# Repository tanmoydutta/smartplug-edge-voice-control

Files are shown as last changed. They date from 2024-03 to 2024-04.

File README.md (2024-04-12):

# A Module to hack a smart plug with Voice control, using Voice Recognition with Edge Analytics
Orthosie is a NINA-B306 powered Smart Plug controller module. The module contains basic circuitry for interfacing and programming and a PDM microphone for Speech recognition. 



This is a replacement / hacking module for modern smart plugs using ESP02S or CB2S modules from Tuya.


The diagram below shows the pinout of the module including programming and debug contact interfaces (USB Serial and Software Debug)
<p align="center">
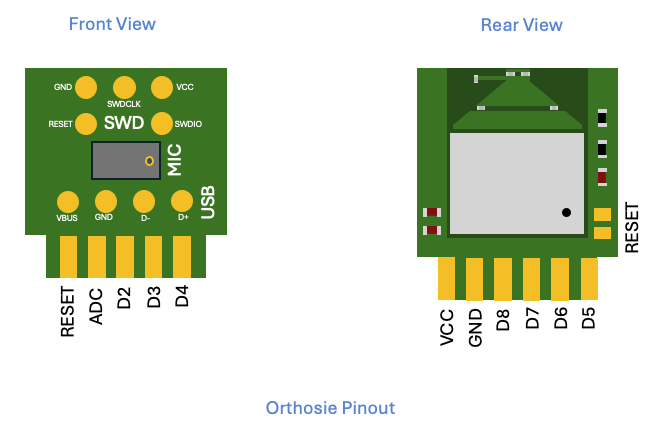
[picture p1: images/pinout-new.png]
Pinout Orthosie pinout
  
</p>

The contact interfaces (SWD and USB) can be connected to programming interface and devices using Pogo pin connectors with the help of suitable clips as shown below in the image.
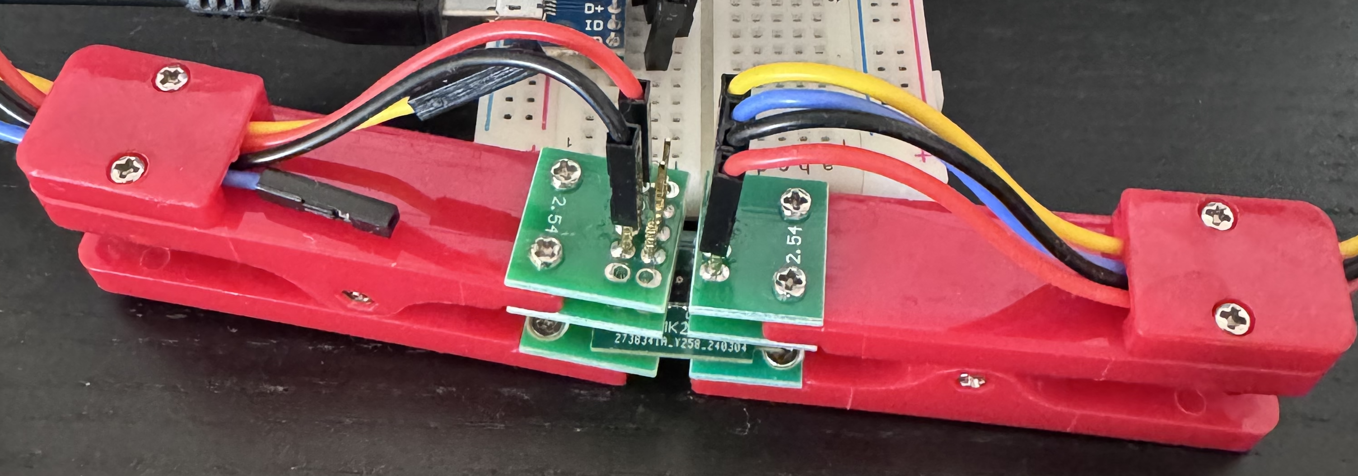
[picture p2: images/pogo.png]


The purpose of this module is to add a 'voice recognition on edge' capability to a Smart Plug. The NINA module also provides BLE capability and makes communication and control via BLE also possible.
<p align="center">
  Factory installed
  Hacked!
</p>

This is an Open Source Hardware certified by OSHWA - 

<p align="center">
  <a href="https://certification.oshwa.org/nl000019.html">
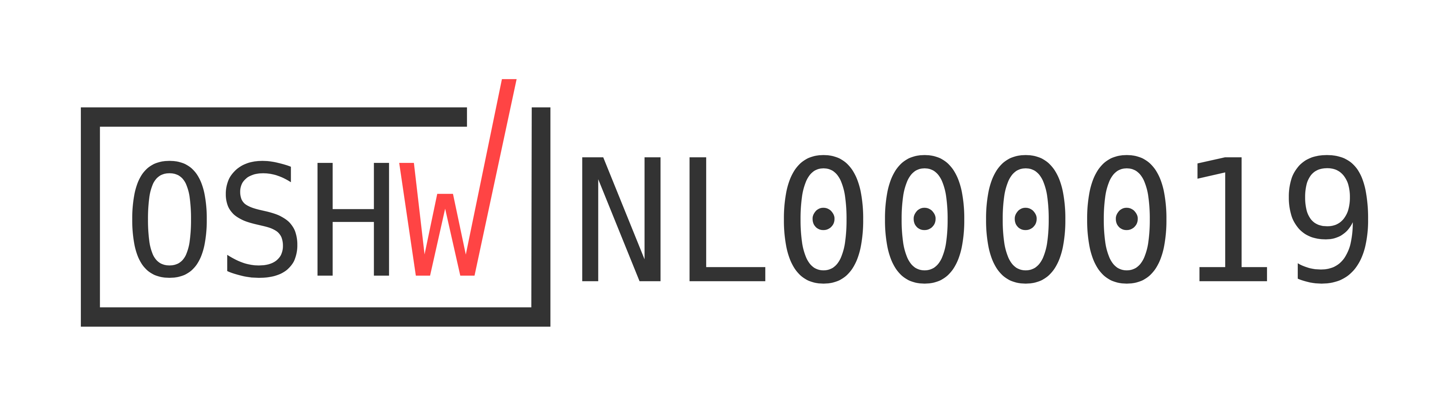
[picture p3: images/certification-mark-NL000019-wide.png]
OSHWA OSHWA Certification
    
  </a>
</p>



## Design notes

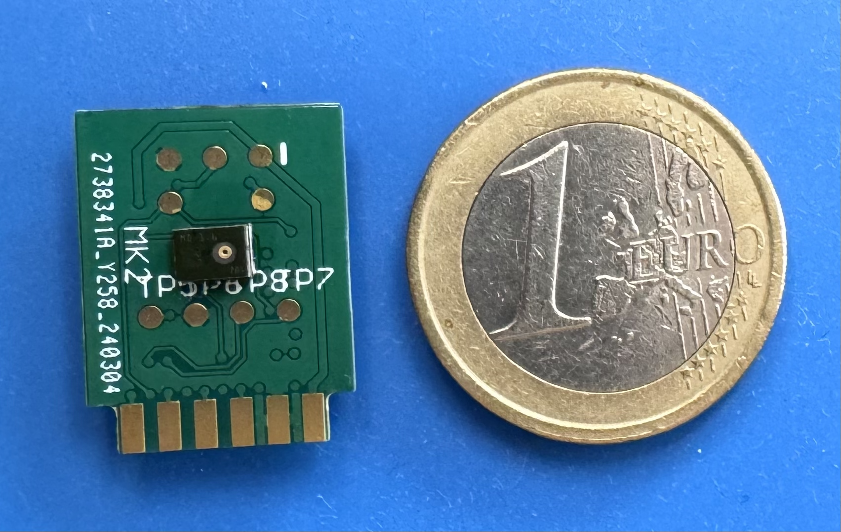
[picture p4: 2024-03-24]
images/orthosie_1euro.png

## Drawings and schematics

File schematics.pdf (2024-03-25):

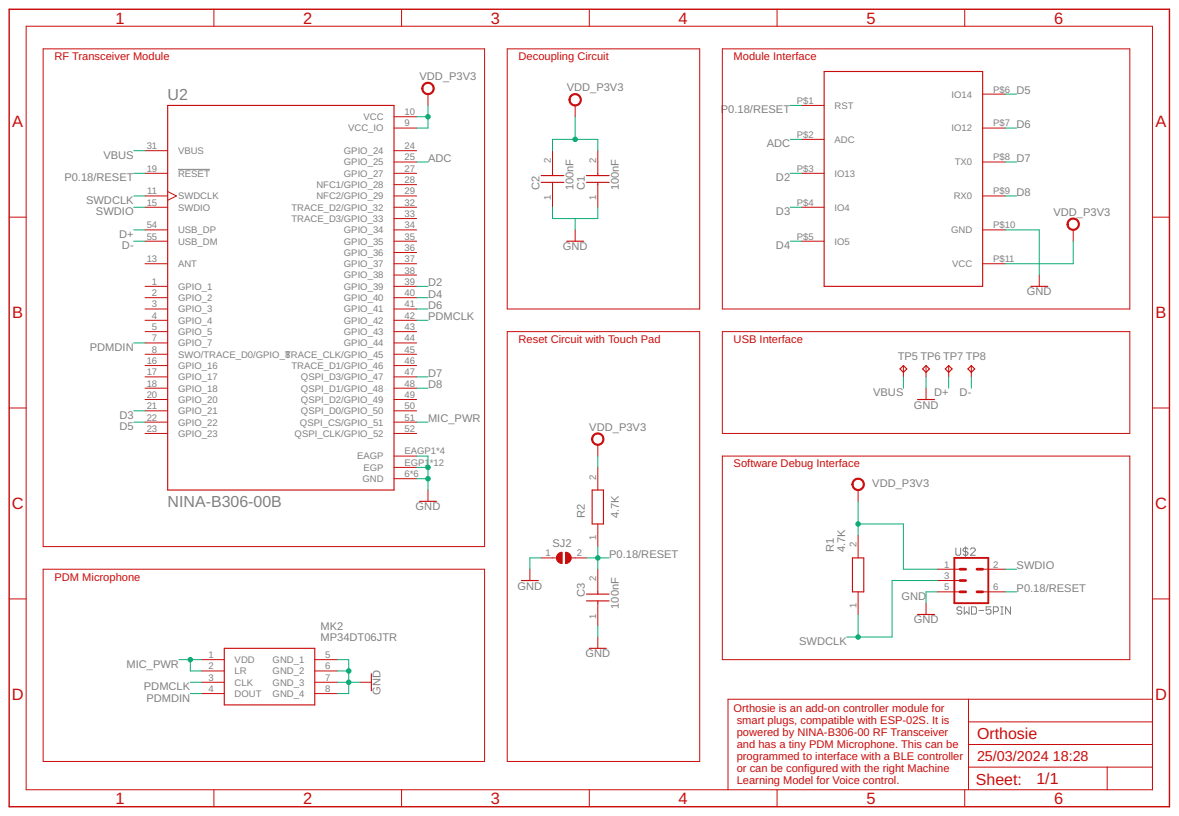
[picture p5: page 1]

Reset Circuit with Touch Pad

Orthosie is an add-on controller module for smart plugs, compatible with ESP-02S. It is powered by NINA-B306-00 RF Transceiver and has a tiny PDM Microphone. This can be programmed to interface with a BLE controller or can be configured with the right Machine Learning Model for Voice control.

Sheet: 1/1

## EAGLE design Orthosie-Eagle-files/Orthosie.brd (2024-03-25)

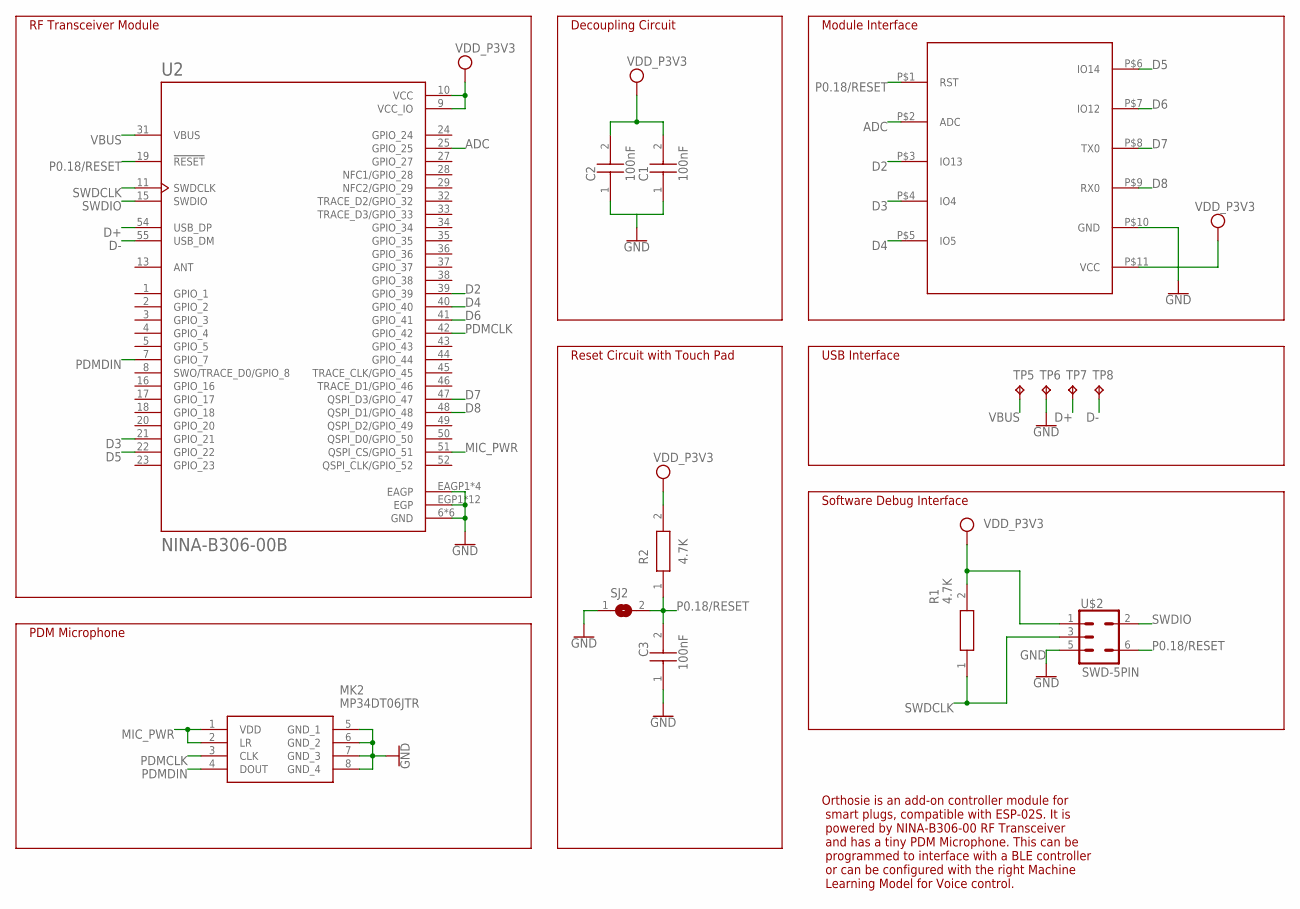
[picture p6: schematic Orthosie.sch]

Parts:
C1, C2, C3: 100nF; CAPC1005X55N
MK2: MP34DT06JTR
R1, R2: 4.7K; RESC1005X40N
SJ2: SJ
TP5, TP6, TP7, TP8: TPB1,27; B1,27
U2: NINA-B306-00B; XCVR_NINA-B306-00B
U$1: ESP02SESP02S_MIRROR; ESP02S_MIRROR
U$2: SWD-5PIN; PAD_05_03X2_TP_NO4

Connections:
ADC: U2.25 (GPIO_25), U$1.P$2 (ADC)
D2: U2.39 (GPIO_39), U$1.P$3 (IO13)
D3: U2.21 (GPIO_21), U$1.P$4 (IO4)
D4: U2.40 (GPIO_40), U$1.P$5 (IO5)
D5: U2.22 (GPIO_22), U$1.P$6 (IO14)
D6: U2.41 (GPIO_41), U$1.P$7 (IO12)
D7: U2.47 (QSPI_D3/GPIO_47), U$1.P$8 (TX0)
D8: U2.48 (QSPI_D1/GPIO_48), U$1.P$9 (RX0)
D+: TP7.TP, U2.54 (USB_DP)
D-: TP8.TP, U2.55 (USB_DM)
GND: C1.1, C2.1, C3.1, MK2.5 (GND_1), MK2.6 (GND_2), MK2.7 (GND_3), MK2.8 (GND_4), SJ2.1, TP6.TP, U2.6 (GND), U2.12 (GND), U2.14 (GND), U2.26 (GND), U2.30 (GND), U2.53 (GND), U2.EAGP1 (EAGP), U2.EAGP2 (EAGP), U2.EAGP3 (EAGP), U2.EAGP4 (EAGP), U2.EGP1 (EGP), U2.EGP2 (EGP), U2.EGP3 (EGP), U2.EGP4 (EGP), U2.EGP5 (EGP), U2.EGP6 (EGP), U2.EGP7 (EGP), U2.EGP8 (EGP), U2.EGP9 (EGP), U2.EGP10 (EGP), U2.EGP11 (EGP), U2.EGP12 (EGP), U$1.P$10 (GND), U$2.5
MIC_PWR: MK2.1 (VDD), MK2.2 (LR), U2.51 (QSPI_CS/GPIO_51)
P0.18/RESET: C3.2, R2.1, SJ2.2, U2.19 (!RESET), U$1.P$1 (RST), U$2.6
PDMCLK: MK2.3 (CLK), U2.42 (GPIO_42)
PDMDIN: MK2.4 (DOUT), U2.7 (GPIO_7)
SWDCLK: R1.1, U2.11 (SWDCLK), U$2.3
SWDIO: U2.15 (SWDIO), U$2.2
VBUS: TP5.TP, U2.31 (VBUS)
VCC: C1.2, C2.2, R1.2, R2.2, U2.9 (VCC_IO), U2.10 (VCC), U$1.P$11 (VCC), U$2.1

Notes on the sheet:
PDM Microphone
RF Transceiver Module
Decoupling Circuit
Reset Circuit with Touch Pad
Module Interface
USB Interface
Software Debug Interface
Orthosie is an add-on controller module for smart plugs, compatible with ESP-02S. It is powered by NINA-B306-00 RF Transceiver and has a tiny PDM Microphone. This can be programmed to interface with a BLE controller or can be configured with the right Machine Learning Model for Voice control.

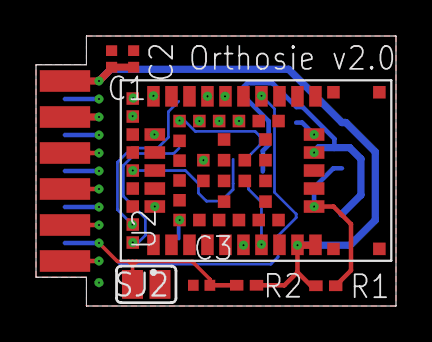
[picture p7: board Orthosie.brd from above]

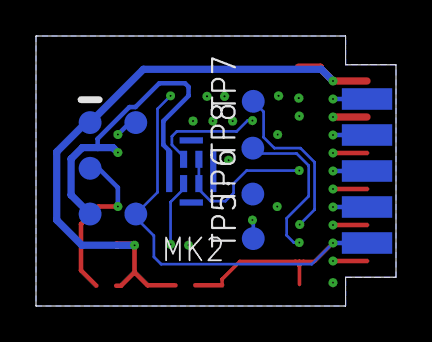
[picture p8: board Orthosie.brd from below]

Board: 6 copper layers, 20.0 x 15.0 mm, 14 parts (6 on the bottom side), 19 nets.

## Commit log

2024-03-24 Adding Eagle files
    [Orthosie.brd, Orthosie.sch]
2024-03-25 pogo connector image added
2024-03-25 Update README.md
    Added image for the pogo connector
2024-03-25 Pin Correction
    [Orthosie.brd, Orthosie.sch]

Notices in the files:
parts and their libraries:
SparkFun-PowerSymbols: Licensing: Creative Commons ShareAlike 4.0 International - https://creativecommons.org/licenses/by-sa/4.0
